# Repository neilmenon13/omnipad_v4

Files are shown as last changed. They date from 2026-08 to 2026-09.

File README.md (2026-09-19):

# Omni Pad

Omni Pad is a compact 3×4 macropad PCB with 12 MX-compatible keys, two push-capable rotary encoders, and addressable RGB underglow. It is built around an RP2040 Zero and is intended for custom shortcuts, media controls, editing workflows, and other keyboard automation.

> **Hardware revision:** The KiCad design and manufacturing outputs are named `macropad_v3`, while this repository is the `omnipad_v4` project.

## Features

- 12 MX-compatible soldered keys arranged in a 3×4 matrix
- 2 × Bourns PEC11R-4215F-S0024 rotary encoders with push switches
- RP2040 Zero controller
- 4 × WS2812B addressable RGB LEDs for underglow
- Through-hole key switches and encoders
- Hand-solder-friendly 0805 capacitors
- KiCad schematic and PCB layout
- Gerber and drill files ready for PCB manufacturing
- 3D-printable upper and lower case models

## Repository layout

```text
.
├── BOM.csv                  Component list and sourcing metadata
├── models/
│   ├── Upper Case.stl       3D-printable top case
│   └── Bottom Case.stl      3D-printable bottom case
└── pcb/
    ├── kicad/
    │   ├── macropad_v3.kicad_pro   KiCad project
    │   ├── macropad_v3.kicad_sch   Schematic
    │   └── macropad_v3.kicad_pcb   PCB layout
    └── gerber/               Gerber archive for manufacturing
        └── gerbers.zip       PCB manufacturing ZIP
```

## Bill of materials

The complete component list is available in [`BOM.csv`](BOM.csv). The main electrical components are:

| Part | Quantity | Notes |
| --- | ---: | --- |
| MX-compatible switches | 12 | `MX_Solder_1.00u` footprint |
| Switch diodes | 12 | SOD-123 footprint |
| PEC11R-4215F-S0024 encoders | 2 | Rotary encoder with integrated push switch |
| WS2812B LEDs | 4 | Addressable RGB underglow |
| RP2040 Zero | 1 | Main controller |
| Capacitors | 4 | 0805 hand-solder footprint |

Check the schematic, footprint assignments, and manufacturer datasheets before ordering parts. The BOM is the source of truth for the current design revision.

## Building the hardware

### 1. Review the design

Open `pcb/kicad/macropad_v3.kicad_pro` with KiCad. Use the schematic to review the switch matrix, encoder connections, RP2040 Zero pin assignments, power, and WS2812B LED chain before fabrication.

### 2. Order the PCB

Download the manufacturing archive at [`pcb/gerber/gerbers.zip`](pcb/gerber/gerbers.zip). The ZIP contains:

- Copper, solder-mask, paste, and silkscreen Gerbers
- Board outline (`macropad_v3-Edge_Cuts.gbr`)
- PTH and NPTH drill files
- The Gerber job file

If your manufacturer supports it, upload the complete ZIP as-is so the layer and drill files stay together.

### 3. Assemble the board

A typical assembly order is:

1. Solder the RP2040 Zero and other small SMD components.
2. Solder the WS2812B underglow LEDs, observing their data direction and polarity.
3. Solder the 12 switch diodes.
4. Solder the two rotary encoders.
5. Solder the 12 MX-compatible switches.
6. Inspect for shorts and verify power and ground before connecting USB.

### 4. Print the case

The matching case parts are in [`models/`](models/). Print `Upper Case.stl` and `Bottom Case.stl`, then test-fit the PCB before final assembly. Confirm dimensions and mounting hardware against the case before committing to the final print.

## Firmware

This repository currently contains the hardware design, manufacturing files, BOM, and case models. It does **not** include keyboard firmware or a keymap.

After assembly, the RP2040 Zero will need firmware configured for the 3×4 key matrix, both rotary encoders, their push switches, and the WS2812B underglow chain. A firmware project such as QMK or KMK can be used to map the keys and encoder functions.

## Design tools

- [KiCad](https://www.kicad.org/) for the schematic and PCB
- A Gerber viewer for checking manufacturing outputs
- A 3D-printing slicer for the case models

## Status

Omni Pad is a hardware design project. Review the schematic and PCB carefully, verify the BOM with your preferred suppliers, and perform an electrical inspection before powering a freshly assembled board.

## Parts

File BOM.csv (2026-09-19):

Reference | Qty | Value | DNP | Exclude from BOM | Exclude from Board | Footprint | Datasheet | DK_Datasheet_Link | DK_Detail_Page
C1,C2,C3,C4 | 4 | C |  |  |  | Capacitor_SMD:C_0805_2012Metric_Pad1.18x1.45mm_HandSolder
D1,D2,D3,D4,D5,D6,D7,D8,D9,D10,D11,D12 | 12 |  |  |  |  | ScottoKeebs_Components:Diode_SOD-123
D13,D14,D15,D16 | 4 | WS2812B |  |  |  | LED_SMD:LED_WS2812B_PLCC4_5.0x5.0mm_P3.2mm | https://cdn-shop.adafruit.com/datasheets/WS2812B.pdf
S1,S2,S3,S4,S5,S6,S7,S8,S9,S10,S11,S12 | 12 |  |  |  |  | ScottoKeebs_Scotto:MX_Solder_1.00u
S13,S14 | 2 | PEC11R-4215F-S0024 |  |  |  | digikey-footprints:Rotary_Encoder_Switched_PEC11R | https://www.bourns.com/docs/Product-Datasheets/PEC11R.pdf | https://www.bourns.com/docs/Product-Datasheets/PEC11R.pdf | /product-detail/en/bourns-inc/PEC11R-4215F-S0024/PEC11R-4215F-S0024-ND/4499665
U2 | 1 | RP2040_Zero |  |  |  | ScottoKeebs_MCU:RP2040_Zero

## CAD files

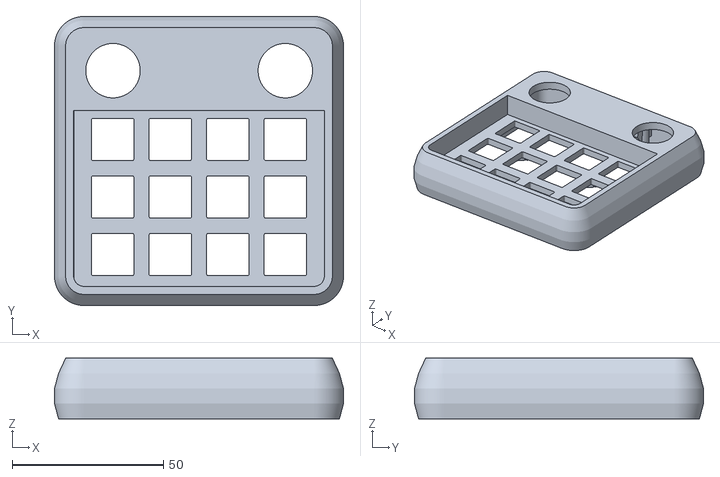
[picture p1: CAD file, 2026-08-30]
models/Upper Case.stl
95.6 x 95.6 x 20.1

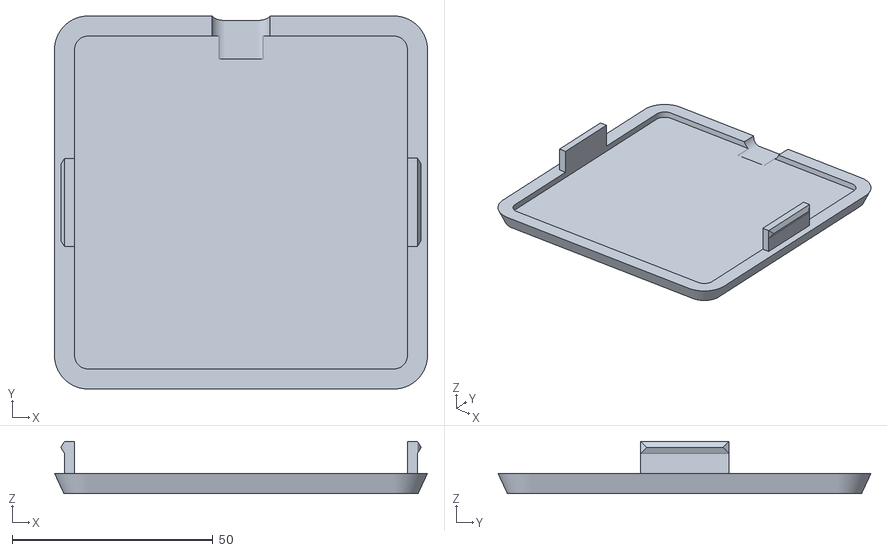
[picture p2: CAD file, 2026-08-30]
models/Bottom Case.stl
93.0 x 93.0 x 13.0

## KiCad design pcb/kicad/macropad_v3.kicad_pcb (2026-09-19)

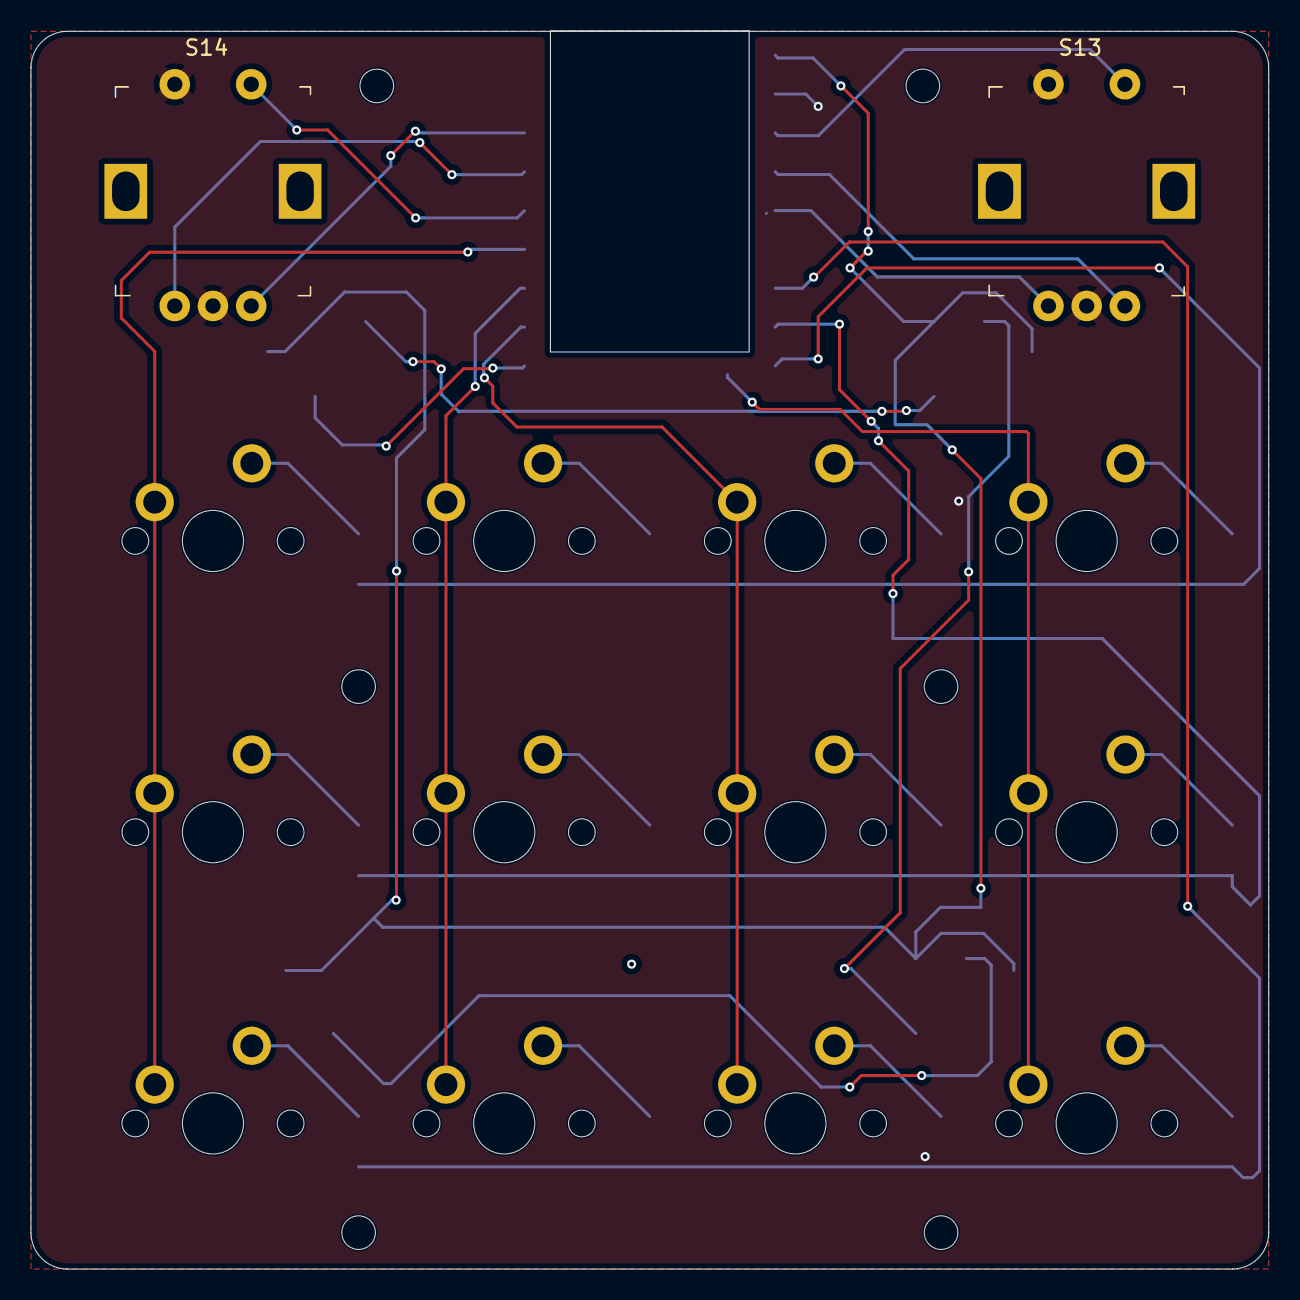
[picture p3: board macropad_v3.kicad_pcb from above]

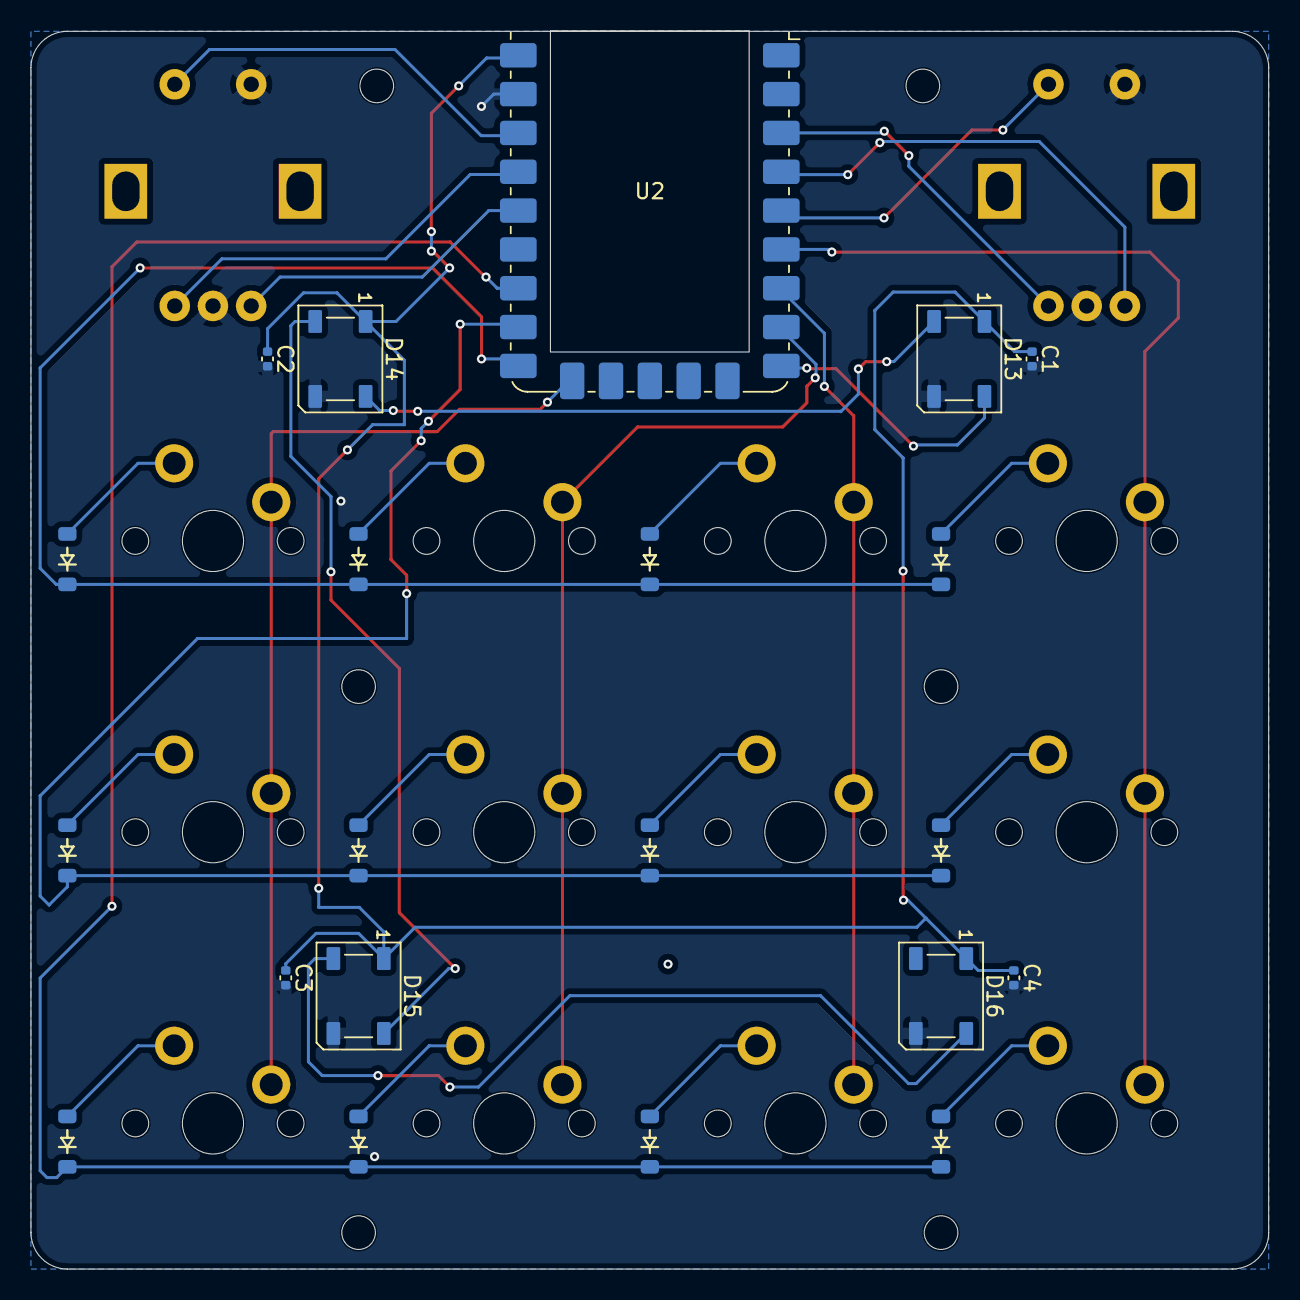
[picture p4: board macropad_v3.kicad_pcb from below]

Board: 2 copper layers, 81.0 x 81.0 mm, 41 parts (21 on the bottom side), 31 nets.

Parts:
C1, C2, C3, C4: C; C_0402_1005Metric
D1, D2, D3, D4, D5, D6, D7, D8, D9, D10, D11, D12: Diode_SOD-123
D13, D14, D15, D16: WS2812B; LED_WS2812B_PLCC4_5.0x5.0mm_P3.2mm
H1, H2, H3, H4, H5, H6: MountingScrew; MountingHole_2.2mm_Tight
S1, S2, S3, S4, S5, S6, S7, S8, S9, S10, S11, S12: MX_Solder_1.00u
S13, S14: PEC11R-4215F-S0024; Rotary_Encoder_Switched_PEC11R
U2: RP2040_Zero; MCU_RP2040-Zero_SMD

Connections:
+5V: C1.1, C2.1, C3.1, C4.1, D13.1 (VDD), D14.1 (VDD), D15.1 (VDD), D16.1 (VDD), U2.23 (5V)
/COL 0: S1.1, S5.1, S9.1, U2.6 (5)
/COL 1: S2.1, S6.1, S10.1, U2.7 (6)
/COL 2: S3.1, S7.1, S11.1, U2.8 (7)
/COL 3: S4.1, S8.1, S12.1, U2.14 (13)
/ENC_A: S13.A (CH_A), U2.19 (28)
/ENC_A_2: S14.A (CH_A), U2.4 (3)
/ENC_B: S13.B (CH_B), U2.20 (29)
/ENC_B_2: S14.B (CH_B), U2.3 (2)
/ENC_SW: S13.2, U2.21 (3V3)
/ENC_SW_2: S14.2, U2.5 (4)
/RGB_DATA: D13.4 (DIN), U2.9 (8)
/ROW 0: D1.1 (K), D2.1 (K), D3.1 (K), D4.1 (K), U2.15 (14)
/ROW 1: D5.1 (K), D6.1 (K), D7.1 (K), D8.1 (K), U2.16 (15)
/ROW 2: D9.1 (K), D10.1 (K), D11.1 (K), D12.1 (K), U2.17 (26)
GND: C1.2, C2.2, C3.2, C4.2, D13.3 (VSS), D14.3 (VSS), D15.3 (VSS), D16.3 (VSS), S13.1, S13.C (COM), S14.1, S14.C (COM), U2.22 (GND)
unnamed: D1.2 (A), S1.2
unnamed: D2.2 (A), S2.2
unnamed: D3.2 (A), S3.2
unnamed: D4.2 (A), S4.2
unnamed: D5.2 (A), S5.2
unnamed: D6.2 (A), S6.2
unnamed: D7.2 (A), S7.2
unnamed: D8.2 (A), S8.2
unnamed: D9.2 (A), S9.2
unnamed: D10.2 (A), S10.2
unnamed: D11.2 (A), S11.2
unnamed: D12.2 (A), S12.2
unnamed: D13.2 (DOUT), D14.4 (DIN)
unnamed: D14.2 (DOUT), D15.4 (DIN)
unnamed: D15.2 (DOUT), D16.4 (DIN)

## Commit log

2026-08-30 Uploaded case CAD files
    [Bottom Case.stl, Upper Case.stl]
2026-08-30 Rename Bottom Case.stl to models/Bottom Case.stl
    [Bottom Case.stl]
2026-08-30 Rename Upper Case.stl to models/Upper Case.stl
    [Upper Case.stl]
2026-09-19 Adding KiCAD PCB files
    [macropad_v3.kicad_pcb, macropad_v3.kicad_sch]
2026-09-19 Add BOM.csv
    [BOM.csv]
2026-09-19 Added Gerbers zip fiel
2026-09-19 Update README to refer to the PCB gerber ZIP archive in pcb/gerber instead of the old manufacture folder
